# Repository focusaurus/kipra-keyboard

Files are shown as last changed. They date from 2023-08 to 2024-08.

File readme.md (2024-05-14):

# kipra: It's kinda pragmatic.

A split ergonomic mechanical keyboard built with ergogen, kicad, and freecad.

There's a [blog post with details on this build](https://peterlyons.com/problog/2024/05/kipra-keyboard/) on my blog.

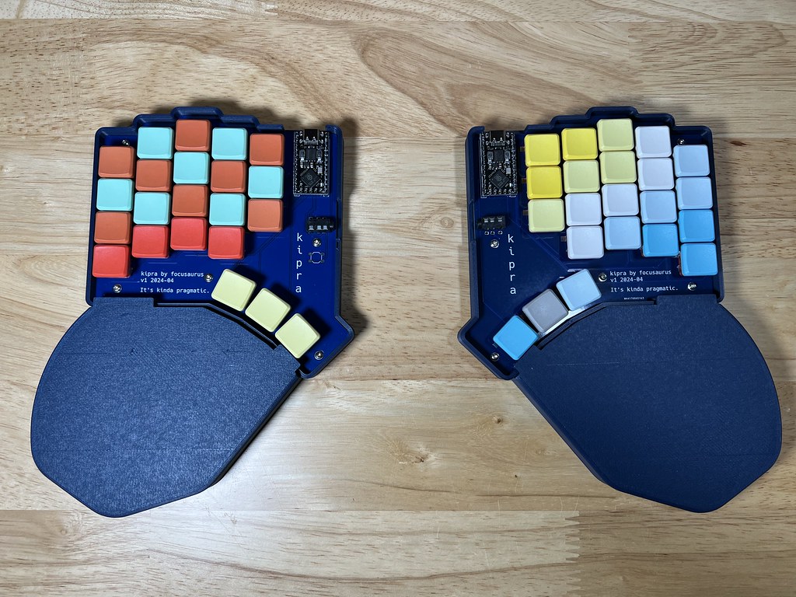
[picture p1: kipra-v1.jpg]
kipra v1


## What's in this repository

- The ergogen file at `v1/kipra-v1.ergogen.yaml`
- FreeCAD files for the case, palm rest, and various jigs and smaller parts
- The kicad PCB project files which were generated initially with ergogen then edited in kicad to route the tracks, add silkscreen, etc.
- Some reference pinout images for the RP2040 MCU I used
- a few screenshots from along the way
- a zip of the gerber files I sent to PCBWay if you just want to order PCBs

# Notes to self

## How to make the test print

- use ergogen via `./bin/build.sh` to output `v1/build/outlines/test_print.dxf`
- In freecad, start a new file and use Draft workbench
- Import the .dxf file. It will create many shapes.
- Select them all and hit the blue up arrow to upgrade them to wires
- Select them all and click the squiggly icon to convert to sketch
- Switch to Part Design Workbench
- Make a new body
- put the sketch in the body
- select the sketch and pad up 6mm

# MCU pinout on RP2040 (compatible)

| Pin | Use | (center) | Use | Pin |
| --- | ----- | --- | --- | --- |
| | | | Col Thumb  | P19 |
| | | | col inner  | P18 |
| P6  | row 4 | | col index  | P15 |
| P7  | row 3 | | col middle | P15 |
| P8  | row 2 | | col ring | P16 |
| P9  | row 1 | | col pinky  | P10 |

# v1 Solder Jumpers

TL;DR this is very confusing because reversible/symmetric PCBs are confusing.

With your PCBs laid out left & right as they will be when the keyboard is built and in use - top side facing up, you solder **ALL 4 COLUMNS OF JUMPERS ON THE PCB TOP SIDES**. None of the jumpers on the bottom side of the PCBs get soldered.

The left and right PCBs are symmetric, but the left and right MCUs are NOT. So to account for that we have do factor that into our pinouts and jumper routing.

Info for reference:

- In kipra v1, the footprint used was: [nice_nano.js from commit 753a](https://github.com/ceoloide/ergogen-footprints/blob/753a3464b552da21bd121a076ddfa4b47fadcfe8/nice_nano.js) in github.com/ceoloide/ergogen-footprints.
- This version did not yet support the `reverse_mount` parameter. If kipra v2 becomes a thing, we'll do that.
- However, the nice_nano footprint is design with the following configuration in mind (which we do NOT want to use in the kipra):
  - you want to mount your MCUs face down (Dunno, many folks like this?)
  - you want the jumper solders on the back so they are out of sight and don't obscure the silkscreen for the MCU pinout labels
- BUT in the case of the kipra v1, I specifically want to mount my MCUs face up because they have on-board reset buttons so flashing them is easy and I don't need a reset button on the main keyboard PCB. I added support for one just in case anyway, but hope to not have to use it. In general, I want to support the trend of the hobbyist MCUs having conveniences built-in so the barrier to build a custom keyboard is lower, and every little bit helps.

## How to: model the case in FreeCad

- start a new file
- switch to the Draft workbench
- import `v1/build/outlines/plate-shape.dxf`
- select all the shapes in the tree view
- click "Upgrade" blue up arrow to get a wire
- click the wire and click the squiggly "convert birectionally from draft to sketch"
- switch to the Part workbench
- select the sketch and select the 2D offset (hidden behind an arrow next to 3D offset)
- set distance to 2.6mm (2.4 for the wall and 0.2 for fit)
  - set the join type to tangent!
- click fill offset
- select the 2D offset in the tree view and click extrude to 10mm

## How to: model the case in FreeCAD (prototype 6)
- start a new file
- switch to the Draft workbench
- import `v1/build/outlines/plate-shape.dxf`
- select all the shapes in the tree view
- click "Upgrade" blue up arrow to get a wire
- click "Upgrade" blue up arrow again to get a face
- Use the offset 2D tool to get an offset 2.4mm from the edge of the face
  - set the join type to tangent!
- extrude that offset up 12mm and click to make a solid
- click the wire and click the squiggly "convert birectionally from draft to sketch"
  - this gives us the outer wall
- extrude the face for the bottow up 2mm
- this is all not exactly right but I was experimenting too quickly to keep track of it

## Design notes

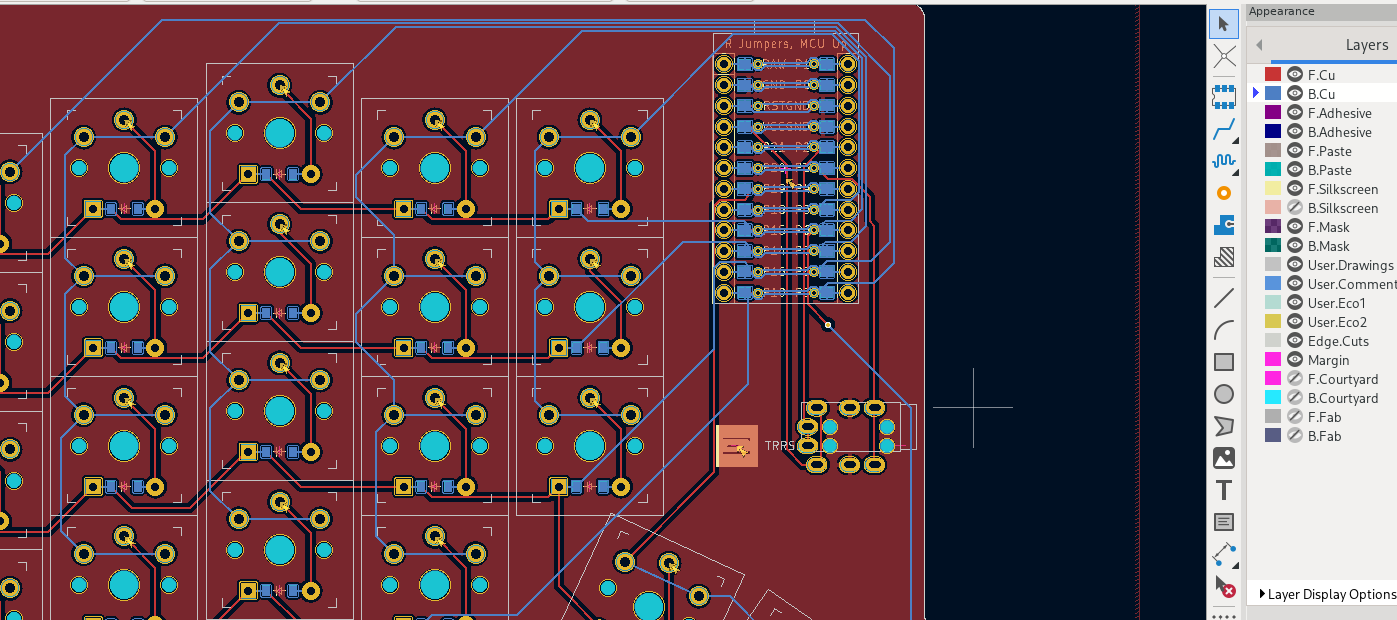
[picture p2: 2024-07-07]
v2/kicad-trace-layout-2024-07-07.png

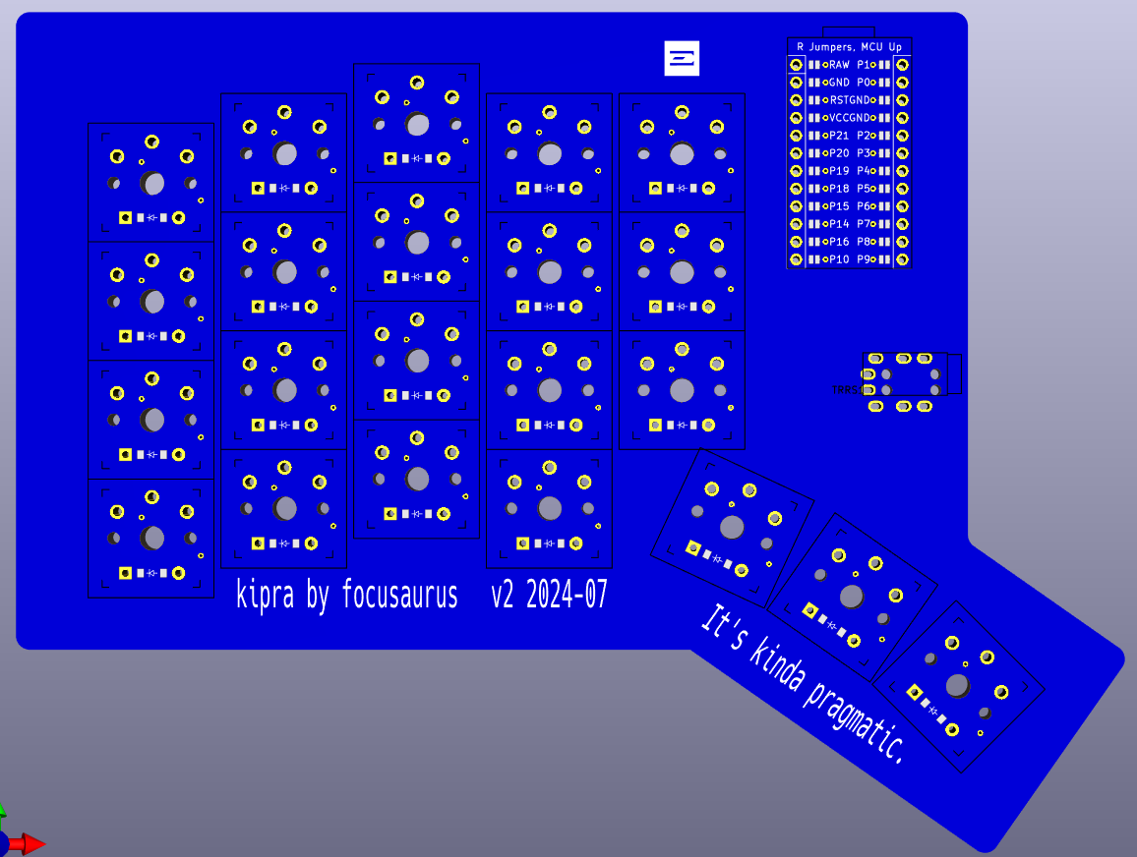
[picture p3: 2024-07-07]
v2/kicad-preview-3D-2024-06-29.png

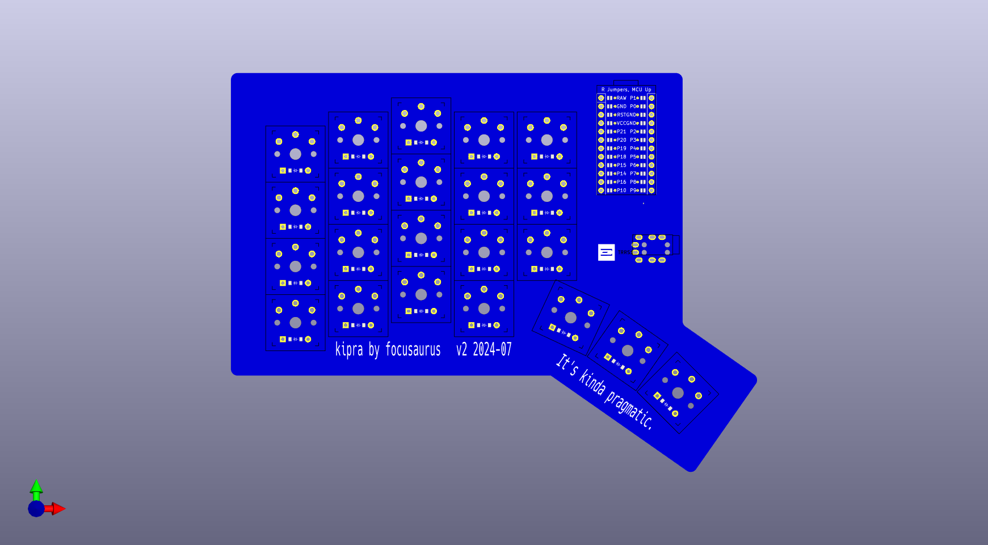
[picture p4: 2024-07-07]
v2/kicad-preview-3D-2024-07-07.png

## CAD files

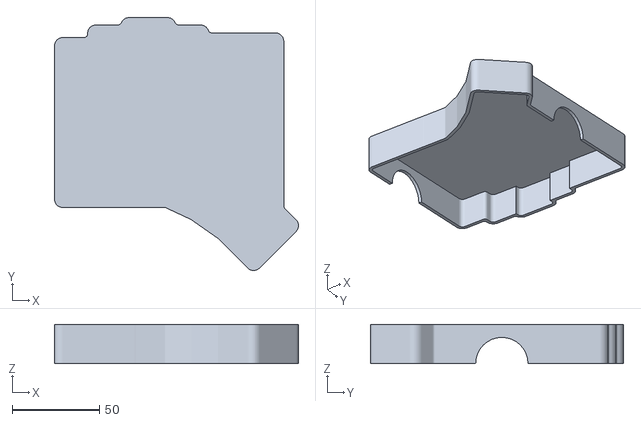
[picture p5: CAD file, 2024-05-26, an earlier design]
v1/case/full_case_top.stl
140.0 x 145.2 x 22.4

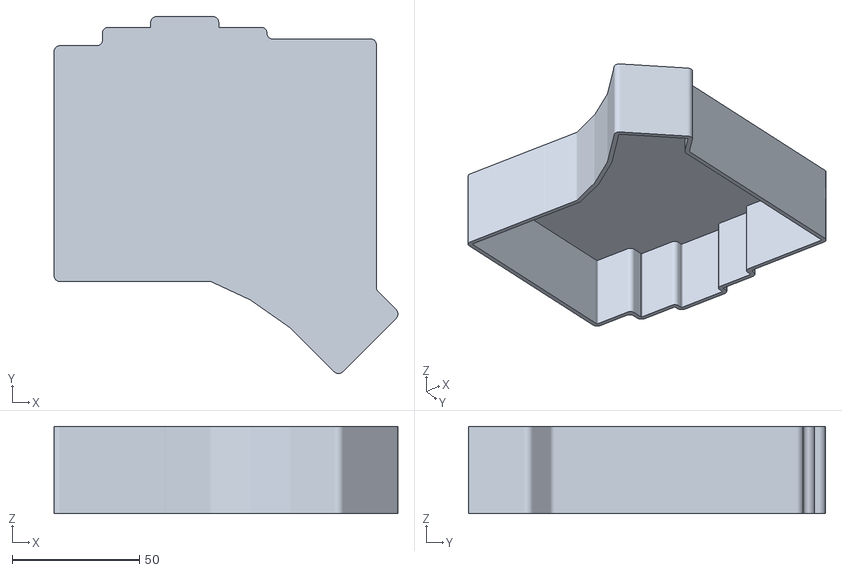
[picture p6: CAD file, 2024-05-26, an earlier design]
v1/case/full_case_bottom.stl
135.3 x 140.4 x 34.4

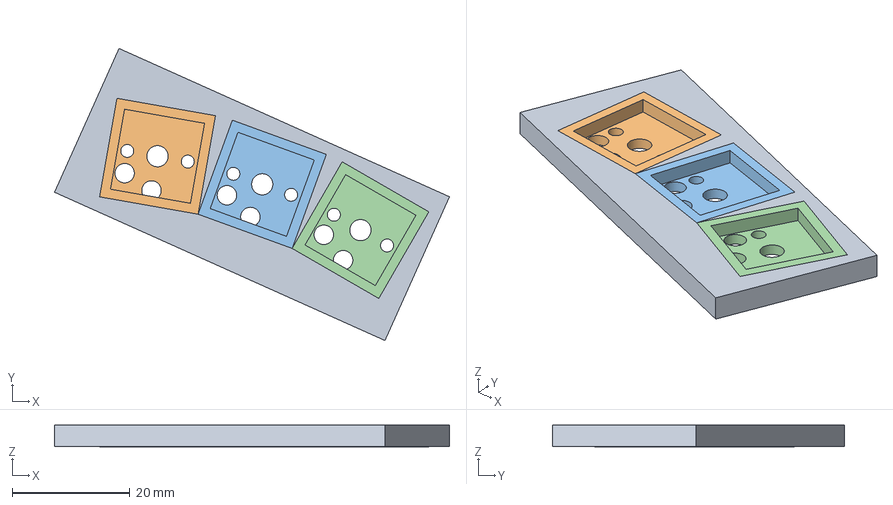
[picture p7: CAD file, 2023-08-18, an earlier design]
v1/jigs/thumb-arc-assembly.FCStd
67.1 x 49.6 x 3.70 mm
thumb-arc-fit-test_001
choc-hotswap-housing_001
choc-hotswap-housing_002
choc-hotswap-housing_003

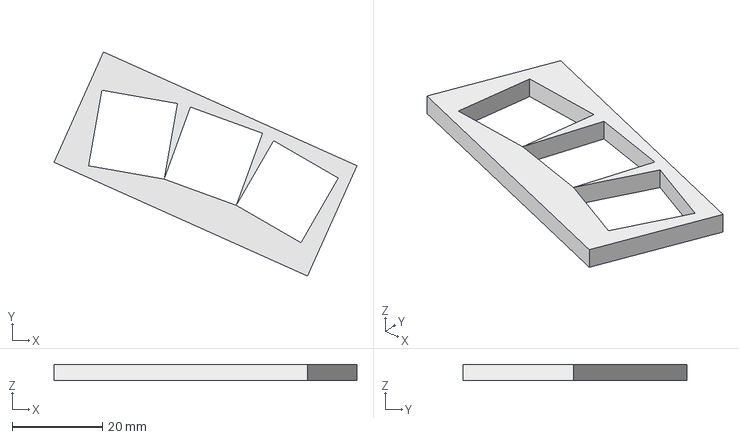
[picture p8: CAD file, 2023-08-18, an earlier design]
v1/jigs/thumb-arc-fit-test.FCStd
67.1 x 49.6 x 3.60 mm

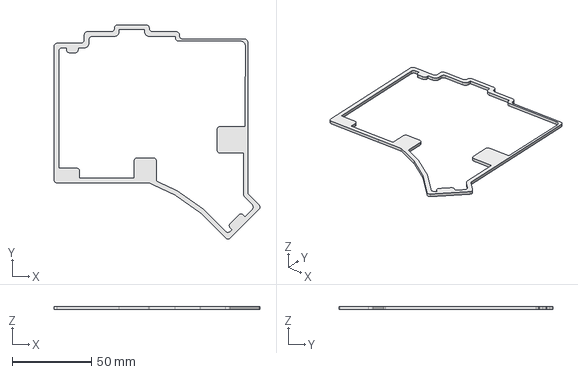
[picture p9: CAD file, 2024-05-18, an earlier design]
v1/case/bottom-plate-1.FCStd
129.6 x 134.8 x 2.00 mm

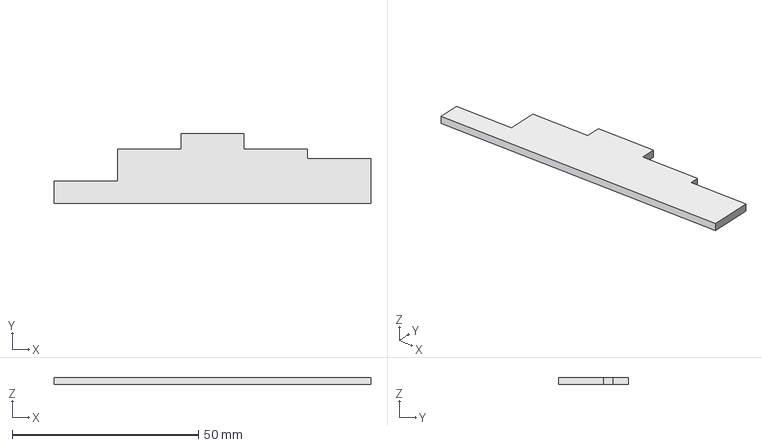
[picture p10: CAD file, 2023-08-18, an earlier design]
v1/jigs/column-stagger-fit-test.FCStd
85.0 x 18.9 x 2.00 mm

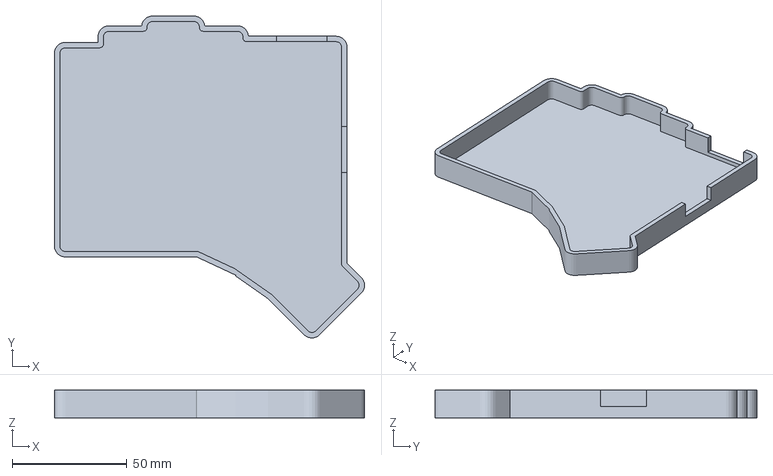
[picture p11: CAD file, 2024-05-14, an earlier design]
v1/case/case-prototype-5b.3mf
135.2 x 140.4 x 12.0 mm

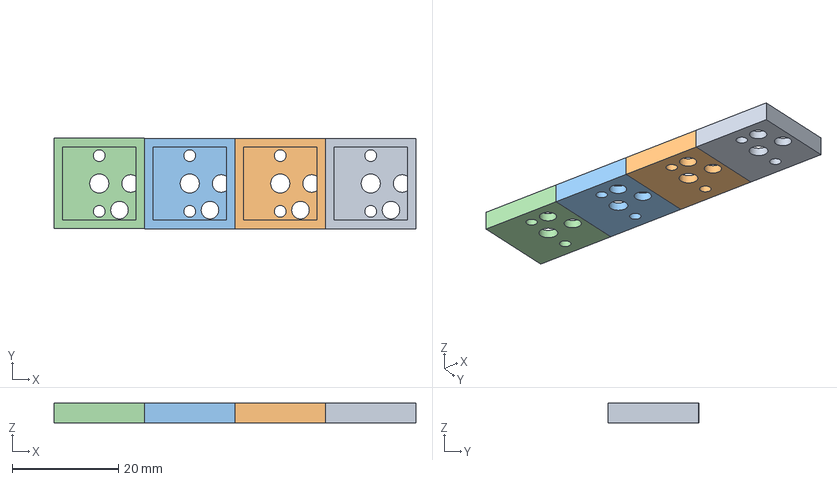
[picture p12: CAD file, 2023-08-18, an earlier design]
v1/jigs/choc-column-spacing-1x4.FCStd
68.0 x 17.0 x 3.70 mm
choc-hotswap-housing_001
choc-hotswap-housing_002
choc-hotswap-housing_003
choc-hotswap-housing_004

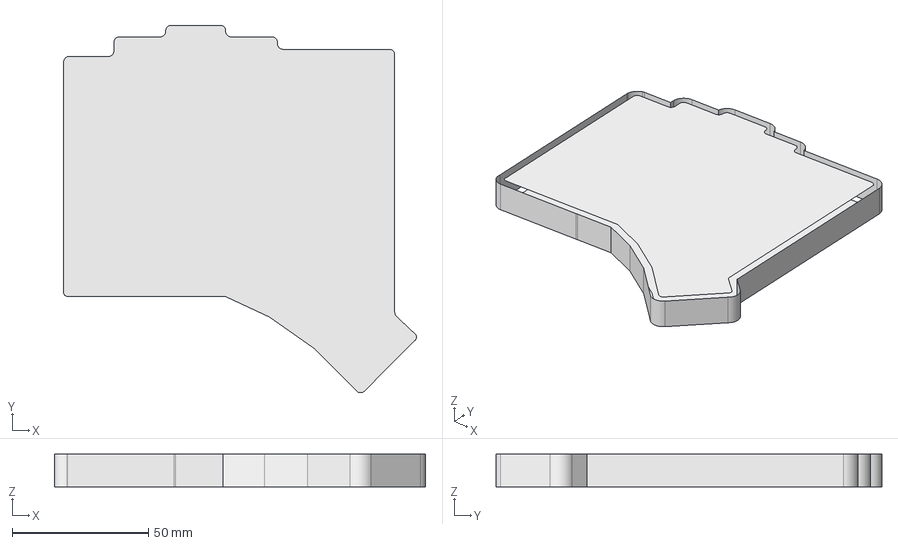
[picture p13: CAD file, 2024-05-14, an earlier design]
v1/case/case-prototype-2.FCStd
136.2 x 141.5 x 12.0 mm

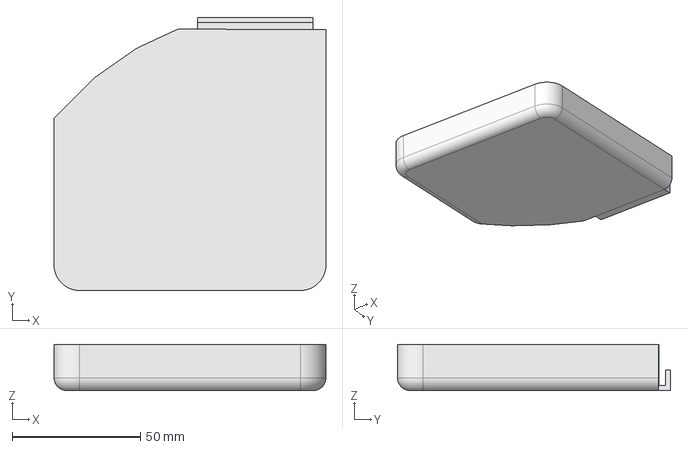
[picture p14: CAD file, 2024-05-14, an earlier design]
v1/case/palm-rest-1.FCStd
106.0 x 106.4 x 18.0 mm

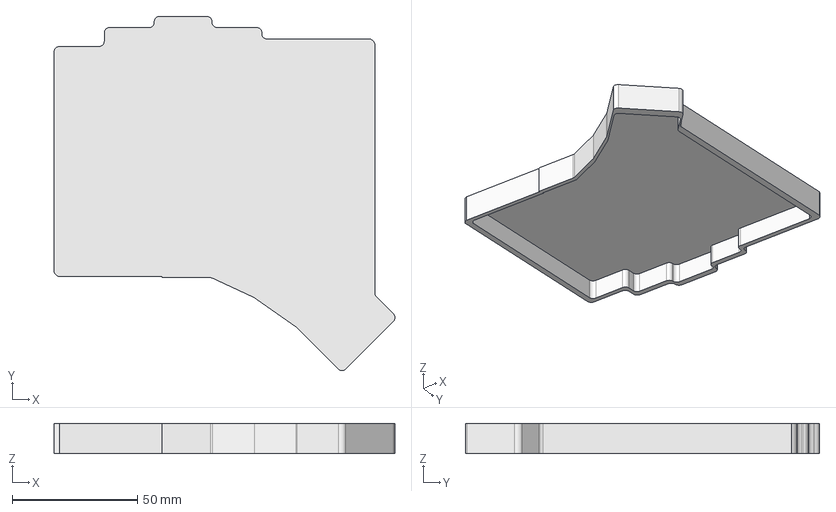
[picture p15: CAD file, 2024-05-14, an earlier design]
v1/case/case-prototype-1.FCStd
136.2 x 141.5 x 12.0 mm

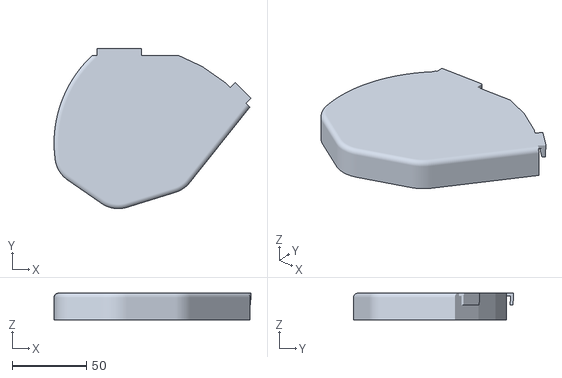
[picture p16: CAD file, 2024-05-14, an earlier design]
v1/case/palm-rest-2b-left.stl
132.5 x 107.8 x 18.0

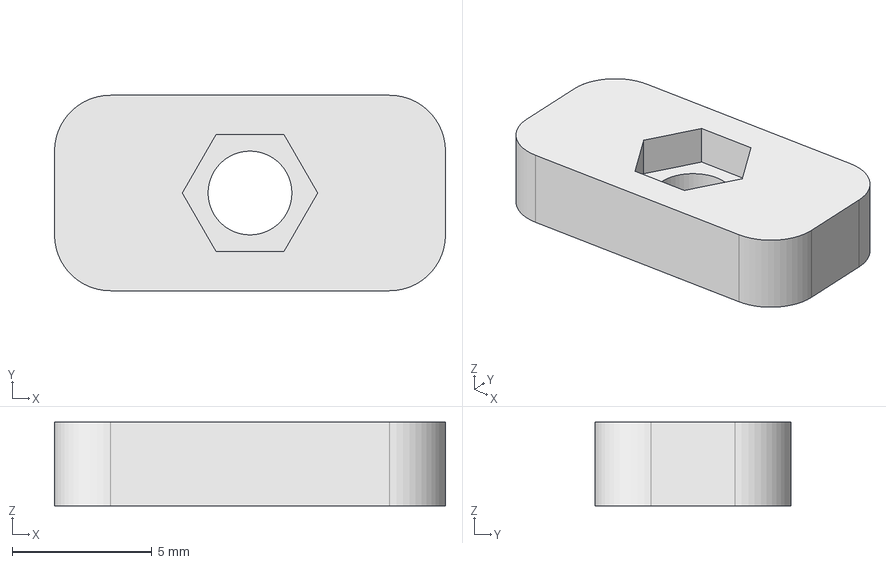
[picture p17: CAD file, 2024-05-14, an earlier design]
v1/case/standoff-m2-hex-a.FCStd
14.0 x 7.00 x 3.00 mm

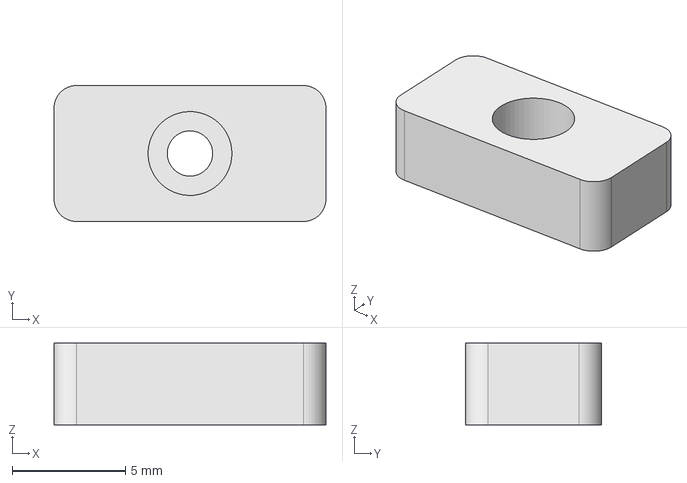
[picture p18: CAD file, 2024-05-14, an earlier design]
v1/case/standoff-m2.FCStd
12.0 x 6.00 x 3.60 mm

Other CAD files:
v1/case/case-prototype-5.FCStd
v1/case/case-clip.FCStd
v1/case/case-prototype-4.FCStd
v1/case/palm-rest-2.FCStd
v1/case/case-clip.stl
v1/case/case-prototype-3.FCStd
v1/case/palm-rest-1.stl
v1/case/palm-rest-2.stl
v1/case/standoff-m2-hex-a.stl
v1/case/standoff-m2.stl
v1/jigs/choc-column-spacing-1x4.stl
v1/jigs/column-stagger-fit-test.stl
v1/jigs/thumb-arc-fit-test.stl

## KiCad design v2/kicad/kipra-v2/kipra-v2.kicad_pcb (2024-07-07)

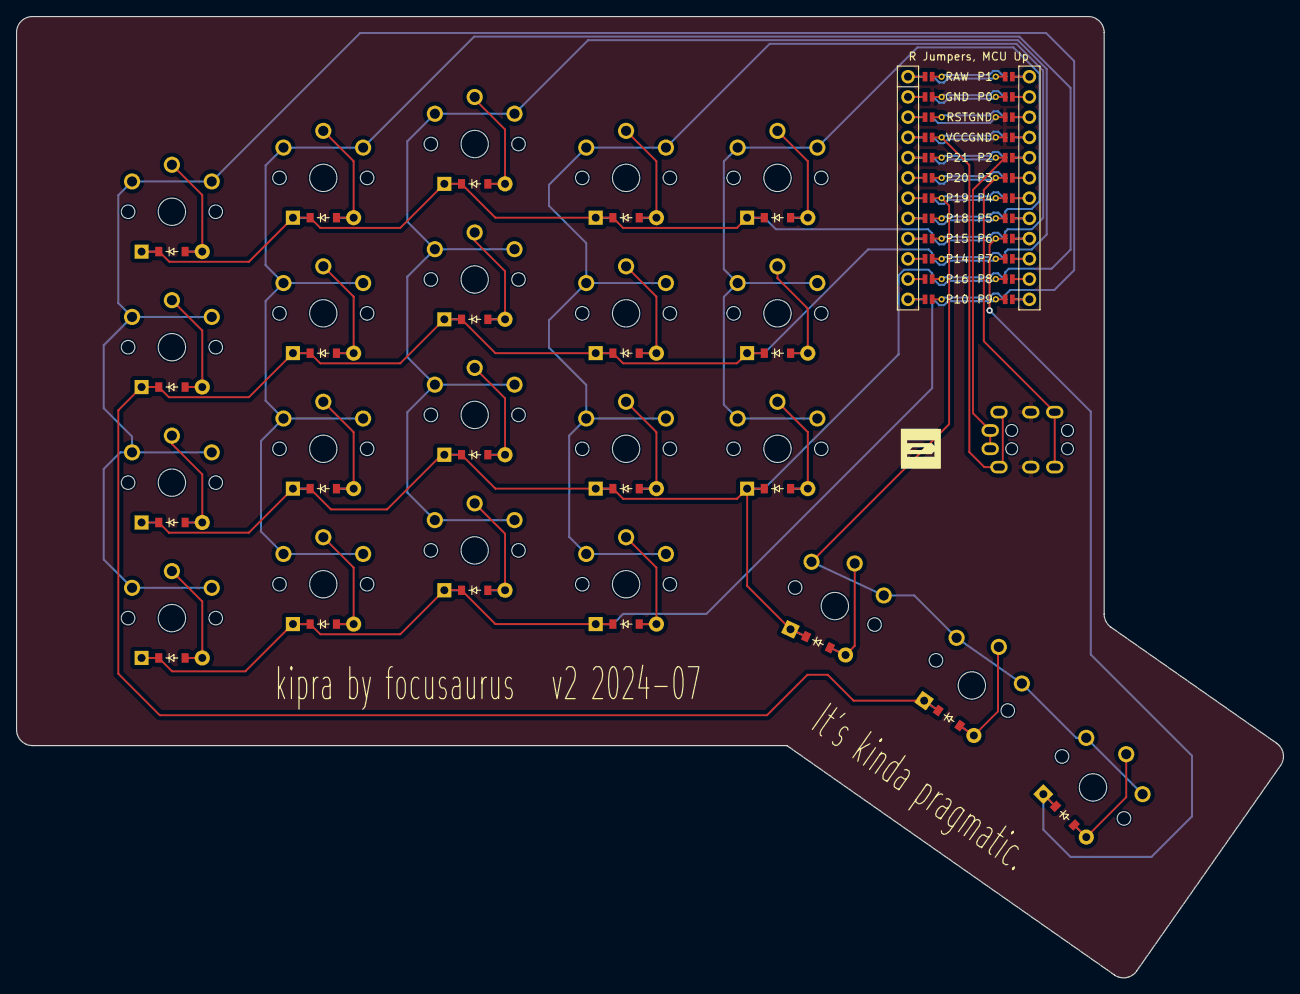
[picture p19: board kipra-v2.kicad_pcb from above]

Board: 2 copper layers, 159.0 x 120.6 mm, 47 parts (0 on the bottom side), 48 nets.

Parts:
D1, D2, D3, D4, D5, D6, D7, D8, D9, D10, D11, D12, D13, D14, D15, D16, D17, D18, D19, D20, D21, D22: ComboDiode
LOGO1: utility_ergogen_logo
MCU1: mcu_nice_nano
S1, S2, S3, S4, S5, S6, S7, S8, S9, S10, S11, S12, S13, S14, S15, S16, S17, S18, S19, S20, S21, S22: PG1350
TRRS1: TRRS-PJ-320A-dual

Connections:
GND: MCU1.103, MCU1.104, MCU1.123, TRRS1.3
MCU1_1: MCU1.1, MCU1.24
MCU1_2: MCU1.2, MCU1.23
MCU1_3: MCU1.3, MCU1.22
MCU1_4: MCU1.4, MCU1.21
MCU1_5: MCU1.5, MCU1.20
MCU1_6: MCU1.6, MCU1.19
MCU1_7: MCU1.7, MCU1.18
MCU1_8: MCU1.8, MCU1.17
MCU1_9: MCU1.9, MCU1.16
MCU1_10: MCU1.10, MCU1.15
MCU1_11: MCU1.11, MCU1.14
MCU1_12: MCU1.12, MCU1.13
P2: MCU1.105, TRRS1.1
P3: MCU1.106, TRRS1.4
P6: D4.1, D8.1, D12.1, D16.1, D19.1, D20.1, MCU1.109
P7: D3.1, D7.1, D11.1, D15.1, D18.1, D21.1, MCU1.110
P8: D2.1, D6.1, D10.1, D14.1, D17.1, D22.1, MCU1.111
P9: D1.1, D5.1, D9.1, D13.1, MCU1.112
P10: MCU1.113, S1.1, S2.1, S3.1, S4.1
P14: MCU1.115, S9.1, S10.1, S11.1, S12.1
P15: MCU1.116, S13.1, S14.1, S15.1, S16.1
P16: MCU1.114, S5.1, S6.1, S7.1, S8.1
P18: MCU1.117, S17.1, S18.1, S19.1
P19: MCU1.118, S20.1, S21.1, S22.1
VCC: MCU1.121, TRRS1.2
index_four: D16.2, S16.2
index_one: D13.2, S13.2
index_three: D15.2, S15.2
index_two: D14.2, S14.2
inner_four: D19.2, S19.2
inner_three: D18.2, S18.2
inner_two: D17.2, S17.2
middle_four: D12.2, S12.2
middle_one: D9.2, S9.2
middle_three: D11.2, S11.2
middle_two: D10.2, S10.2
pinky_four: D4.2, S4.2
pinky_one: D1.2, S1.2
pinky_three: D3.2, S3.2
pinky_two: D2.2, S2.2
ring_four: D8.2, S8.2
ring_one: D5.2, S5.2
ring_three: D7.2, S7.2
ring_two: D6.2, S6.2
thumb_far: D20.2, S20.2
thumb_middle: D21.2, S21.2
thumb_near: D22.2, S22.2

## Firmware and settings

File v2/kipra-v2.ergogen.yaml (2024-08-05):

metadata:
  version: 2.0.0
  author: Peter Lyons
  www: https://peterlyons.com
units:
  # choc spread is just a LITTLE too tight for me,
  # so bump it up by 1mm
  # This is by coincidence the same as "u" but "cx + 1"
  # expresses the intent more clearly
  $default_spread: cx + 1
  # I definitely want minimal vertical padding though
  # so "cy" here is choc y
  $default_padding: cy
  # "proxy" width and height variables
  kx: cx
  ky: cy
  stagger: 0.25ky
  bb: 7 # bind base
  txtheight: 4
  txtwidth: 2
points:
  key:
    tags.1u: true
    bind: [bb,bb,bb,bb]
  zones:
    fingers:
      anchor:
        shift: [100, -100]
      columns:
        pinky.key.column_net: P10
        pinky.rows.four.bind: [bb+(2stagger),bb,bb,1.5bb]
        pinky.rows.three.bind: [bb,bb,bb,1.5bb]
        pinky.rows.two.bind: [bb,bb,bb,1.5bb]
        pinky.rows.one.bind: [bb,bb,bb,1.5bb]
        ring.key:
          stagger: stagger
          column_net: P16
        ring.rows.one.bind: [bb,bb,bb+stagger,bb]
        ring.rows.four.bind: [bb+stagger,bb,bb,bb]
        middle.key:
          stagger: stagger
          column_net: P14
        middle.rows.one.bind: [bb,bb,bb+(2stagger),bb]
        index.key:
          stagger: -stagger
          column_net: P15
        index.rows.one.bind: [bb,0,bb+stagger,bb]
        index.rows.four.bind: [bb+stagger,0,bb,bb]
        inner.key:
          column_net: P18
        inner.rows.one.skip: true
        inner.rows.two.bind: [bb,32,bb+ky+stagger,bb]
        inner.rows.three.bind: [bb,32,bb,bb]
        inner.rows.four.bind: [bb+stagger,32,bb,bb]
      rows:
        one:
          row_net: P9
        two:
          row_net: P8
        three:
          row_net: P7
        four:
          row_net: P6
    thumb:
      anchor:
        ref: fingers_inner_two
        shift: [2.2cx, -2.5cy]
      columns.thumb.key.column_net: P19
      rows:
        far:
          rotate: -45
          row_net: P6
          bind: [0,0,0,0]
        middle:
          rotate: 10
          shift: [-1.1cx, -1.1cy]
          bind: [bb,1.5bb+kx,1.5bb,bb]
          row_net: P7
        near:
          rotate: 10
          shift: [-1.1cx, -1.1cy]
          bind: [0,0,0,0]
          row_net: P8
outlines:
  pcb_shape:
    main:
      what: rectangle
      where: true
      size: kx
      bound: true
      fillet: 2
  switch_cutouts:
    main:
      what: rectangle
      where: true
      size: 13.8
  test_print:
    - name: pcb_shape
    - name: switch_cutouts
      operation: subtract
  pcb_shrunk:
    main:
      what: rectangle
      where: true
      size: kx
      bound: true
      fillet: 2
      expand: -3
  liner_shape:
    - name: pcb_shape
    - name: pcb_shrunk
      operation: subtract
  case_bottom:
    main:
      what: rectangle
      where: true
      size: kx
      bound: true
      fillet: 2
      expand: 2.4
  case_bottom_void:
    main:
      what: rectangle
      where: true
      size: kx
      bound: true
      fillet: 2
      expand: 0.4
  case_top:
    main:
      what: rectangle
      where: true
      size: kx
      bound: true
      fillet: 2
      expand: 2.4 + 2.4
  case_top_void:
    main:
      what: rectangle
      where: true
      size: kx
      bound: true
      fillet: 2
      expand: 2.4 + 0.2
  case_top_pull:
    main:
      what: circle
      radius: 15
      where:
        ref: fingers_middle_two
cases:
  liner_template:
    - name: liner_shape
      # diodes are about 1.05 tall and we want to just barely clear that
      extrude: 1.2
  test_print:
    - name: test_print
      extrude: 6
  full_case_bottom:
    - name: case_bottom
      extrude: 32 + 2.4
    - name: case_bottom_void
      extrude: 32
      operation: subtract
  full_case_top:
    - name: case_top
      extrude: 20 + 2.4
    - name: case_top_void
      extrude: 20
      operation: subtract
    - name: case_top_pull
      extrude: 300
      shift: [-100, 0, 0]
      rotate: [0, 90, 0]
      operation: subtract
pcbs:
  kipra-v2:
    outlines:
      main:
        outline: pcb_shape
    footprints:
      keys:
        what: choc
        where: true
        params:
          from: "{{column_net}}"
          to: "{{colrow}}"
          hotswap: false
          reverse: true
          keycaps: true
          traces: false
      diode:
        what: diode
        where: true
        params:
          from: "{{colrow}}"
          to: "{{row_net}}"
        adjust:
          shift: [0, -5]
      mcu:
        what: mcu_nice_nano
        where:
          ref: fingers_inner_four
          shift: [24, 0]
        params:
          reversible: true
          use_rectangular_jumpers: true
      trrs:
        what: trrs
        where:
          ref: fingers_inner_two
          shift: [38, 0]
          rotate: -90
        params:
          reverse: true
          A: P2
          B: VCC
          C: GND
          D: P3
      logo:
        what: utility_ergogen_logo
        where:
          ref: fingers_inner_two
          shift: [kx, 0]
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

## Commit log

2023-05-26 working on ergogen PCB layout for kipra
2023-05-26 figured out default spread and padding
    - $default_spread and $default_padding go under the "units" property
    - got inner finger included in the main fingers zone and skip working
    for row four
2023-08-18 FreeCAD files for fit test parts
    [choc-column-spacing-1x4.FCStd, column-stagger-fit-test.FCStd, thumb-arc-assembly.FCStd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]
2023-08-26 add diodes in ergogen
2023-08-26 got outline integrated into pcb
2023-08-26 added reset button and fixed placement
2023-08-26 mounting holes
    Need to reference a local mountinghole.js footprint in this project from ergogen now
2023-08-26 case bottom jscad
2023-12-17 build case with openscad
2023-12-18 tweak thumb binds and mounting hole offsets
2023-12-18 use nice_nano_pretty MCU footprint
2023-12-19 MCU has on-board reset
    Don't need a button footprint on the PCB
2024-01-24 Add outline for test print
    Thanks to hand_le in absolem club discord for the help
    [outline.dxf, test_print.dxf]
2024-01-26 Tweak thumb arc and pinky stagger based on test print
2024-01-30 Fix mounting holes and add one at end of thumb arc
2024-01-31 add choc footprint with traces
    Need to put this in ergogen branch
2024-02-25 2024-02-25c move thumb arc higher
    [test_print.dxf]
2024-03-17 trace routes up pinky column
    [kipra-kicad.kicad_pcb]
2024-03-17 route traces up ring column
    [kipra-kicad.kicad_pcb]
2024-03-17 route traces up middle column
    [kipra-kicad.kicad_pcb]
2024-03-17 I think maybe I just need ground now
    [kipra-kicad.kicad_pcb]
2024-03-17 only DRC errors are GND filled zone issues
    [kipra-kicad.kicad_pcb]
2024-03-17 all DRC errors fixed
    [kipra-kicad.kicad_pcb]
2024-03-18 Fix net issue by removing leading zeros
    ceoloide on discord says this is why I'm missing some traces
2024-03-20 about to edit kicad pcb file by hand to fix row to mcu traces
    [kipra-kicad.kicad_pcb]
2024-03-20 hand editing pcb file seems to have fixed the row to mcu traces
    [kipra-kicad.kicad_pcb]
2024-03-23 ergogen move mounting hole out of crowded mcu interior
2024-03-23 DRC passes!
    [kipra-kicad.kicad_pcb]
2024-03-24 add silkscreen text
    [kipra-kicad.kicad_pcb]
2024-03-24 added a reset button (ergogen redo)
    Had to go back to ergogen. Will need to redo all the traces now.
    [kipra-kicad.kicad_pcb]
2024-03-25 checkpoint before starting over to move row pins down one slot to the corner
    [kipra-kicad.kicad_pcb]
2024-03-26 cleaned up tracks. no DRC errors.
    Paired with Jesse and Charles from Recurse Center
    [kipra-kicad.kicad_pcb]
2024-03-27 added silkscreen text
    [kipra-kicad.kicad_pcb]
2024-03-30 Add silkscreen texts as separate file
2024-03-30 Updated version from RC pairing with Jesse
    [kipra-kicad.kicad_pcb]
2024-03-30 Tweak row nets and bind +2mm for room next to MCU
2024-03-30 DRC passes
    [kipra-kicad.kicad_pcb]
2024-03-30 kicad done should be ready to go
    [kipra-kicad.kicad_pcb]
2024-04-15 v1 kicad pcb
    [kipra-kicad.kicad_pcb]
2024-04-15 gerber files sent to pcbway
    [kipra-kicad-B_Cu.gbl, kipra-kicad-B_Mask.gbs, kipra-kicad-B_Paste.gbp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]
2024-04-15 photo of MCU face and jumper pad solder instructions
2024-04-21 add correct pinout/footprint image from vendor
2024-05-14 readme updates on case modeling
2024-05-14 major cleanup and reorg of repo filesystem layout
    - kicad and ergogen builds might be broken by this
    [case-clip.FCStd, case-clip.stl, case-prototype-1.FCStd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]
2024-05-14 mark version 1.0.0 in the ergogen yaml file
    [case-prototype-5b.3mf]
2024-05-14 move text silkscreens sinppet into kicad directory
2024-05-14 add gerber file that was sent to fabrication for the 2024-04 v1 build
2024-05-14 add gerber
2024-05-18 add bottom plate
    idea here is to use the mounting holes to bolt this to the PCB, then
    glue a shelf liner to this instead of directly to the hotswap sockets
2024-05-18 bottom plate first session
    [bottom-plate-1.FCStd]
2024-05-18 much better way to make cases
    This will spit out .stl files for a 2-piece travel case.
    Bottom case should fit the PCB and walls are tall enough to just clear
    the keycaps.
    Top case then nests over top of that.
    No closure/lock mechanism yet.
2024-05-19 much nicer full travel case top
2024-05-26 Add travel case .stl generated files for ease
    These can be rebuilt with ergogen, but for folks who want to just
    download and print, adding them to github
    [full_case_bottom.stl, full_case_top.stl]
2024-05-26 v2 start
    - less pinky stagger
    - move thumb arc closer to inner 2
    - outline closer to a rectangle
    - adjust binding accordingly
    [kipra-v2.ergogen.yaml]
2024-05-27 last thumb arc keycap was colliding. Add more clearance.
    [kipra-v2.ergogen.yaml]
2024-05-27 failed experiment with thumb arc beside inner2
    [kipra-v2.ergogen.yaml]
2024-05-27 fix MCU shift
    Want to make sure the USB connector doesn't poke out past the PCB edge
    [kipra-v2.ergogen.yaml]
2024-06-23 increase bind base to 7 for more room for bottom plate
    For some reason ergogen starts throwing an error if bind base is 8
    [kipra-v2.ergogen.yaml]
2024-06-29 wider binding to make room for bottom plate
    [kipra-v2.ergogen.yaml]
2024-06-30 dialed in text and wider binding for bottom plate
    [kipra-v2.ergogen.yaml]
2024-06-30 thinner bottom plate to just clear the diodes
2024-07-07 ceoloide/ergogen-footprints we are using in kipra v2
    These came from github.com/ceoloide/ergogen-footprints
    main branch commit
    commit feb194fbc753aca7074028fcc73a2d617b5975f8 (HEAD -> main,
    origin/main, origin/HEAD)
    Author: Marco Massarelli <marco.massarelli@gmail.com>
    Date: Thu May 23 09:49:54 2024 -0400
    Fix "Items shorting two nets" DRC error highlighted in PR #31
2024-07-07 kipra PCB preview image from KiCAD
2024-07-07 traces: false on choc footprint seems better
2024-07-07 all tracks routed and passing DRC in kicad
    [kipra-v2.kicad_pcb, kipra-v2.kicad_sch]
2024-07-07 tidy tracks so all F.cu go up interior of MCU
    [kipra-v2.kicad_pcb]
2024-08-05 gerbers dir
2024-08-05 move case top finger pull
    It was hitting the corner
